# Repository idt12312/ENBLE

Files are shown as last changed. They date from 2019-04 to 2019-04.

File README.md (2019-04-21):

# ENBLE

ENBLE is the **EN**vironmental sensor which measures temperature, humidity, and air pressure and sends them over **BLE**.
Because it consumes little current, it can work several years.



Using bridge server and [ThingsBooard](https://thingsboard.io/) which are runnning on Raspberry Pi3, 
you can collect data from some ENBLEs and view measurement data via web browser.



## Contents of this repository

This repository consists of two components.

### 1. Sensor 

[**ENBLE/sensor**](sensor/)

It contains PCB design and firmware for a ENBLE device. 
The details is in README.md.

### 2. Bridge Server

[**ENBLE/bridge_server**](bridge_server/)

It constains a bridge between ENBLE and [**ThingsBooard**](https://thingsboard.io/) as a sample code to utilize ENBLE. 
Bridge server listens BLE advertise packets from ENBLEs and sends data to a ThingsBoard server. 
Using ThingsBoard enables you to collect and visualize measured data.

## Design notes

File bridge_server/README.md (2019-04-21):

# ENBLE Bridge Server

This program is a bridge between ENBLE and [**ThingsBooard**](https://thingsboard.io/) as a sample code to utilize ENBLE. 
It listens BLE advertise packets from ENBLEs and sends data to a ThingsBoard server. 
Using ThingsBoard enables you to collect and visualize measured data. 



## How to use
I tested this program on RaspberryPi3.
It may works well on the device which can execute python and has a Bluetooth interface.

Before running bridge_server.py, the following softwares and python packages need to install.

* Python3
* bluepy
* requests
* ThingsBoard

ThingsBoard is not necessary to run on the same device where bridge_server.py runs.

To run this program, you have to do the following.

1. Rename 'config.json.example' 'config.json'.
2. Edit config.json as your environment.
3. Run bridge_server.py.

If some error like the following occures,

```
bluepy.btle.BTLEManagementError: Failed to execute management command 'le on' (code: 20, error: Permission Denied)
```

execute the following.

```
setcap 'cap_net_raw,cap_net_admin+eip' {path_to_python_packages}/site-packages/bluepy/bluepy-helper
```

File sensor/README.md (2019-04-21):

# ENBLE Sensor 

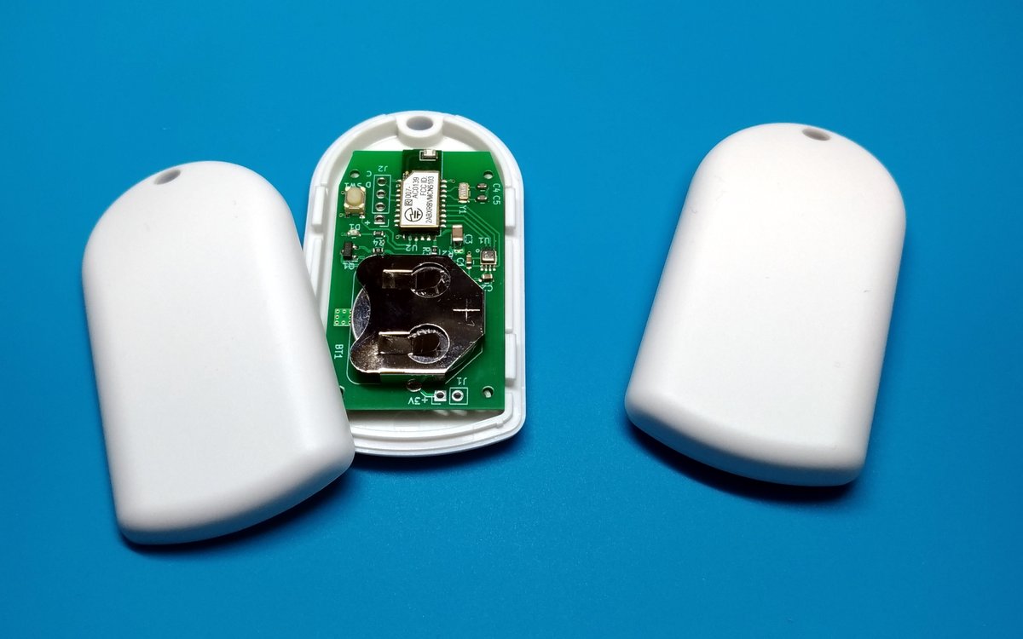
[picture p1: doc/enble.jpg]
ENBLE


This device measures temperature, humidity and pressure using BME280 and send these measured data over BLE advertising and GATT service.
The data format of BLE advertising and GATT service is described bellow.
Using advertising (not using GATT) to collect measured data enables a device to reduce current consumption.  

## BLE Advertise

| Parameter | Value |
|---|---|
| Local Name | "ENBLE" |
| Advertise Interval | 6000ms |
| Manufacturer data  | 10 bytes binary data  |

ENBLE has a push button.
If you push the button, advertising interval change into 100ms.
It is useful to find the specified device which you press the button. 

Manufacturer data has DeviceID and measurement results of sensors.  
Data format is as shown below. 

| Position | Contents | DataType |
|---|---|---|
| byte 0-1 | DeviceID | uint16 |
| byte 2-3 | Battery | uint16 |
| byte 4-5 | Temperature | int16 |
| byte 6-7 | Humidity | uint16 |
| byte 8-9 | Pressure | uint16 |

Each data is contained in **little endian 16bit integer**.  
Means of above data are same as ones in bellow characteristics.

## BLE Services

| Name | Type | Permissions | UUID | DataType |
|---|---|---|---|---|
| ENBLE Service | Service | Read | bff20001-378e-4955-89d6-25948b941062 | |
| DeviceID | Characteristic | Read, Write | bff20011-378e-4955-89d6-25948b941062 | uint16 |
|  Period | Characteristic | Read, Write | bff20012-378e-4955-89d6-25948b941062 | uint16 |
| Battery | Characteristic | Read | bff20021-378e-4955-89d6-25948b941062 | uint16 |
| Temperature | Characteristic | Read | bff20022-378e-4955-89d6-25948b941062 | int16 |
| Humidity | Characteristic | Read | bff20023-378e-4955-89d6-25948b941062 | uint16 |
| Pressure | Characteristic | Read | bff20024-378e-4955-89d6-25948b941062 | uint16 |

### DeviceID
This characteristic indicates a unique number as 16bit unsigned integer. 
The value of this characteristic is stored in nonvolatile memory. 

### Period
This characteristic indicates a sample period of sensors. 
All sensors (battery, temperature, humidity and pressure) sample at the same period. 
This period is 16 bit unsigned integer in seconds. 
The value of this characteristic is stored in nonvolatile memory. 

### Battery
This characteristic indicates battery voltage of the device in mV. 

### Temperature
This characteristic indicates temperature in degC, resolution is 0.01 DegC. 
A negative value is represented in two's complement number. 

### Humidity
This characteristic indicates humidity in %, resolution is 0.1 %.

### Pressure
This characteristic indicates air pressure in Pa, resolution is 10Pa

## Build

### Setup for build
1. Download Nordic SDK ver 12.3.0
2. Place Nordic SDK in firmware/lib  
ex) The structure of directory must be is following.   
    firmware/lib/  
        └──nRF5_SDK_12.3.0_d7731ad/ (this directory name can be anything you like)  
        .       ├──components/  
        .       ├──external/  
        .       ├── ......  

3. Modify NORDIC_SDK_PATH parameter in firmware/Makefile
4. Modify toolchain configuration in 
    * for Linux or OSX user : $(NORDIC_SDK_PATH)/components/toolchain/gcc/Makefile.posix
    * for Windows user : $(NORDIC_SDK_PATH)/components/toolchain/gcc/Makefile.windows

### Build and Flash firmware
This project can be build with GNU MAKE. 
What you need to do for build is executing ```make``` command. 
When you flah a firmware to an ENBLE sensor device, 
connect the device via JLink and execute ```make flash```.

## PCB

I design a PCB with KiCad. 

ENBLE's schematic

The following is a simple block diagram.



I designed PCB to fit in the case, [**TAKACHI PS-65 Seriese**](http://www.takachi-el.co.jp/data/pdf/2016-01-065.pdf). 

### Current consumption

| State | Consumption | Interval |
|---|---|---|
| advertising | 29.4 μC | 6.0 s |
| measuring (start) | 4.14 μC | 60 s |
| measuring (end) | 8.07 μC | 60 s |
| sleeping | 3.80 μA | constantly |

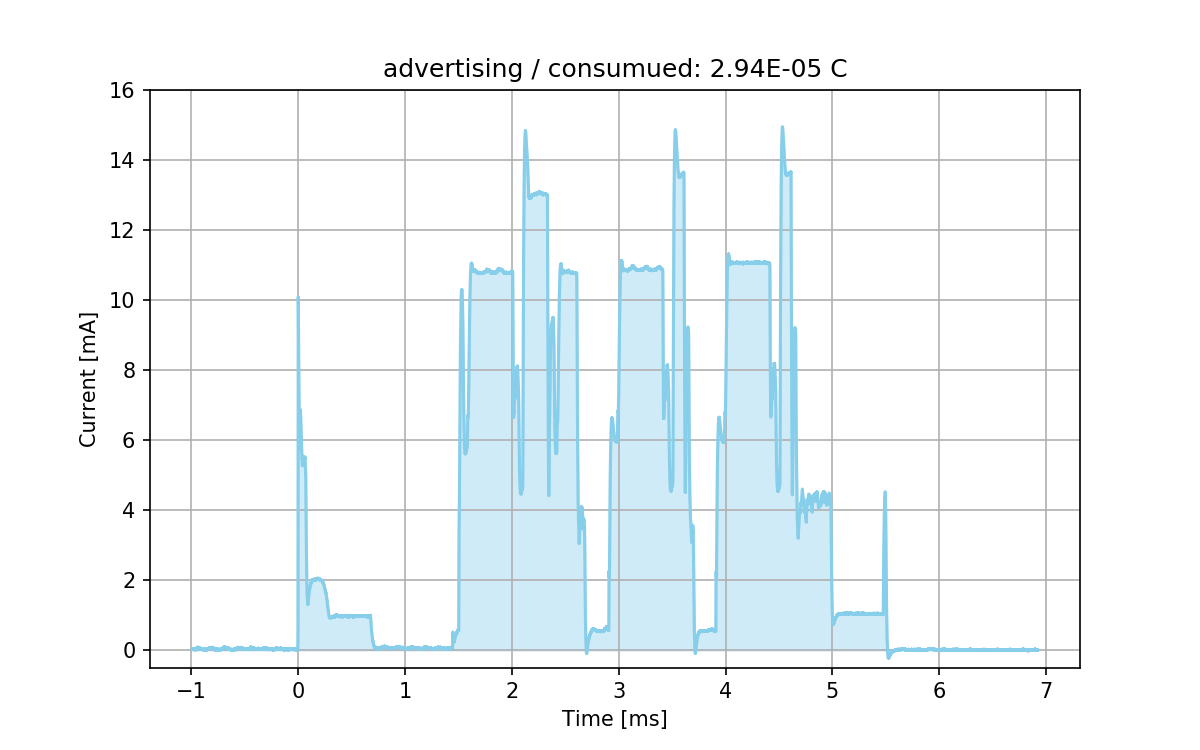
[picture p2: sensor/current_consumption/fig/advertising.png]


<table border="0">
    <tr>
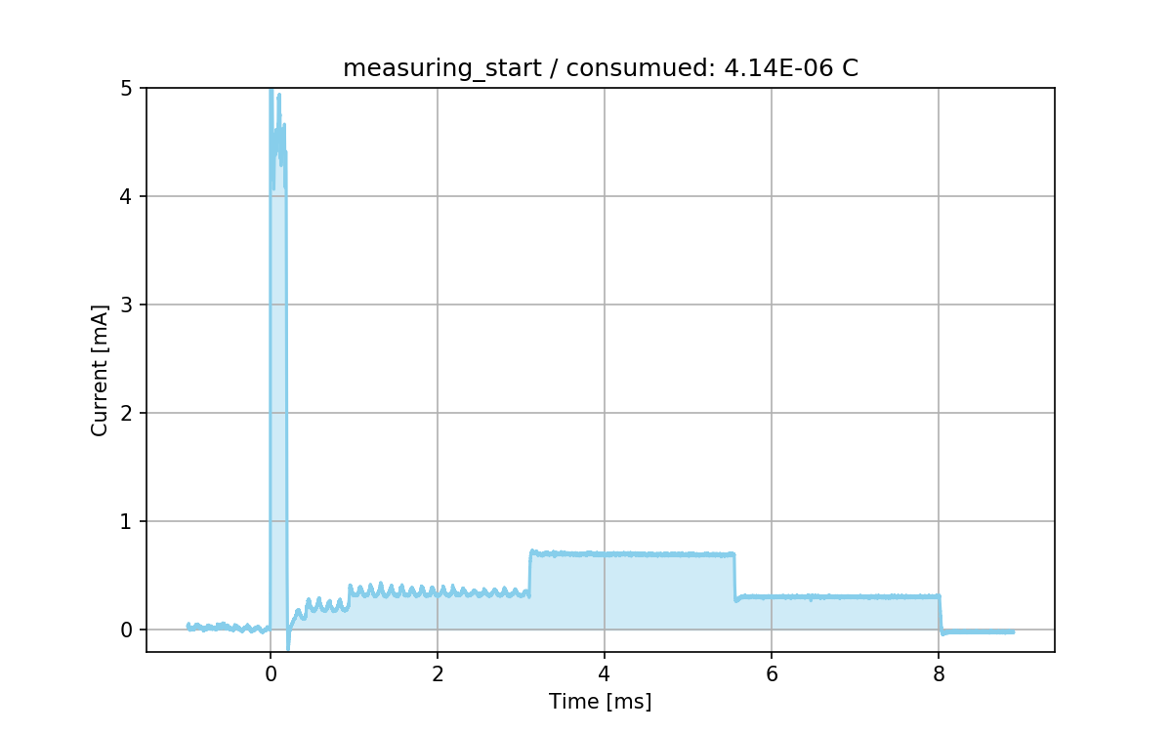
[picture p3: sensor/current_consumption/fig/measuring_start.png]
        <td></td>
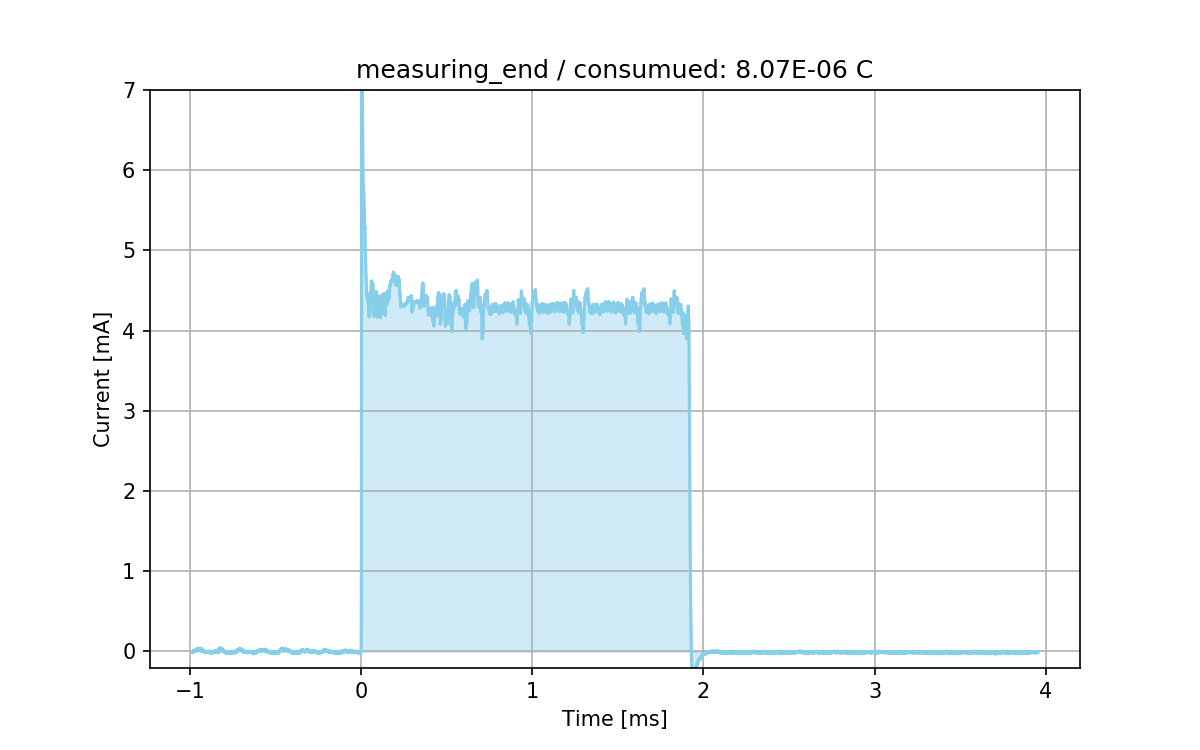
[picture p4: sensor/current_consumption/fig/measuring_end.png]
        <td></td>
    </tr>
</table>

From the above, current consumption per one hour is  
3600 / 6 * 29.4μ + 3600 / 60 * (4.14μ + 8.07μ) + 3600 * 3.8μ = 32.1 mC/h.

Because CR2032 battery charge is 810C(225mAh), 
ENBLE can work in
810 / 31.6e-3 = 25233h (**about 3 years**).

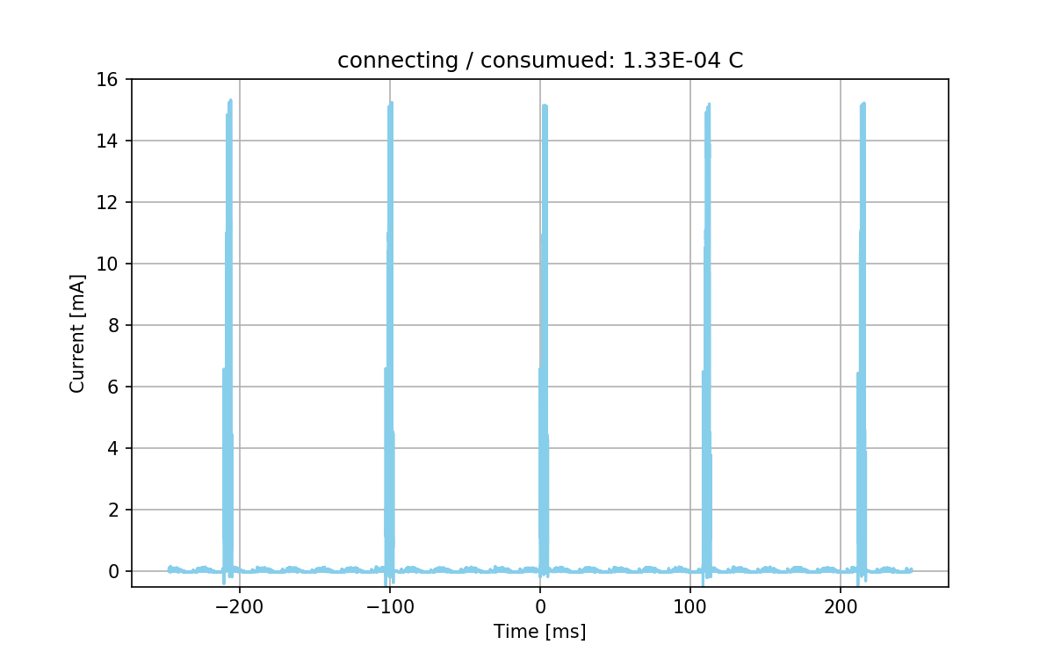
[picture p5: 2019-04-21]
sensor/current_consumption/fig/connecting.png

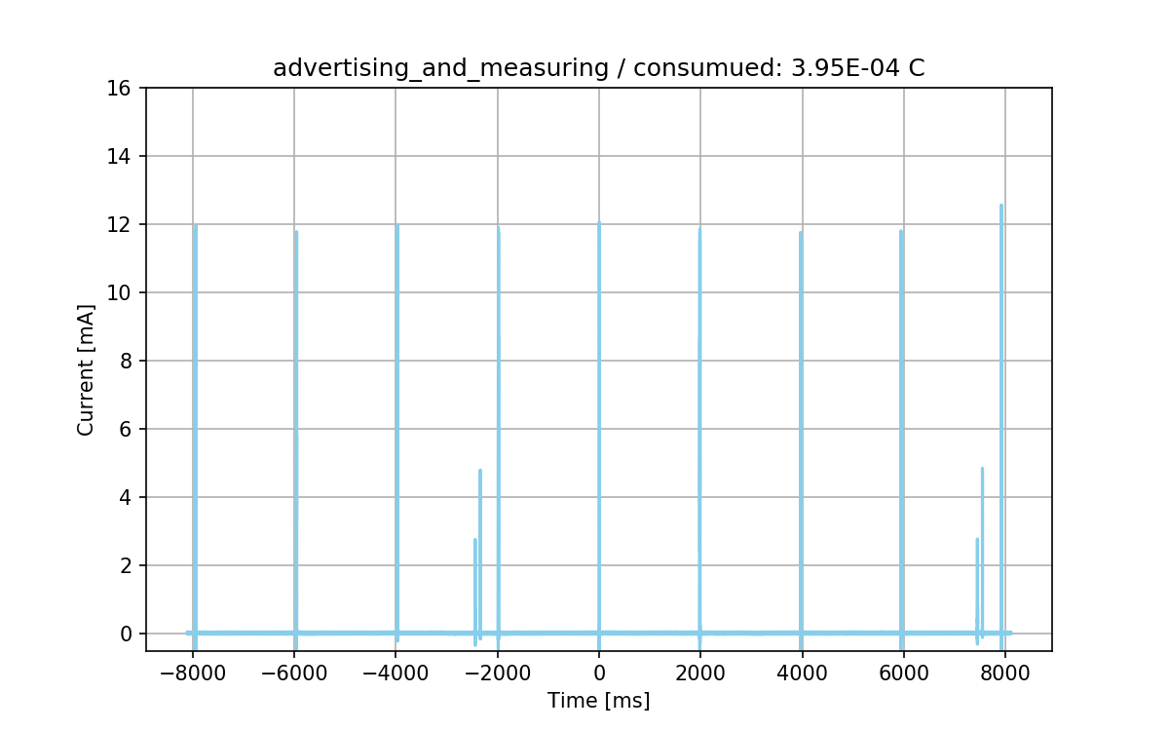
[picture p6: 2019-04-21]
sensor/current_consumption/fig/advertising_and_measuring.png

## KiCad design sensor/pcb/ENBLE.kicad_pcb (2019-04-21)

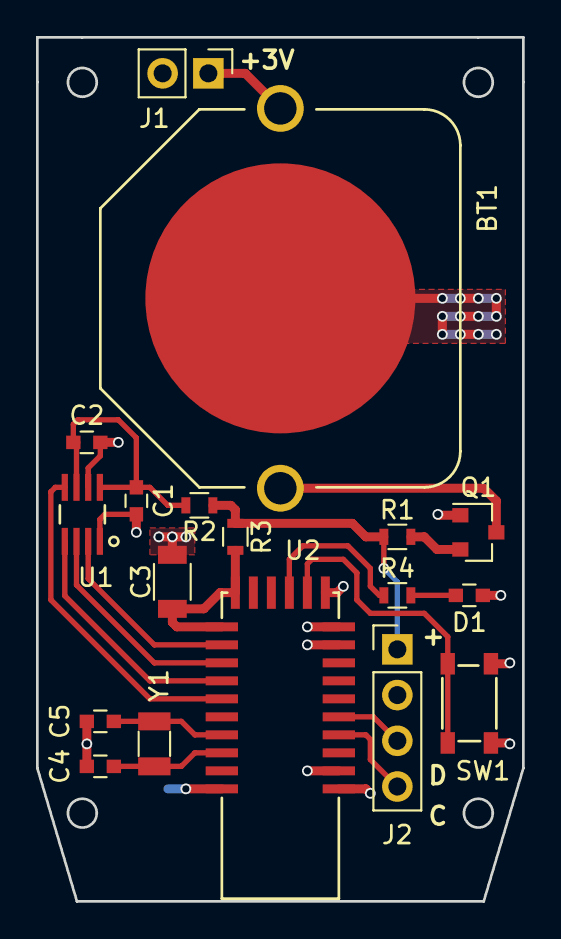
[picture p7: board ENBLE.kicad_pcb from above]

Board: 2 copper layers, 27.0 x 48.0 mm, 18 parts (0 on the bottom side), 17 nets.

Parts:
BT1: CR2032; BK-888
C1, C2: 0.1u; C_0603
C3: 10u; C_1206
C4, C5: 8p; C_0603
D1: LED; C_0603
J1: Conn_01x02; Pin_Header_Straight_1x02_Pitch2.54mm
J2: Conn_01x04; Pin_Header_Straight_1x04_Pitch2.54mm
Q1: SI2333; SOT-23
R1, R2, R3: 0; R_0603
R4: 2.2k; R_0603
SW1: SW_SPST; SKRPACE010
U1: BME280
U2: BVMCN5103-BK
Y1: 32.768kHz; Crystal_SMD_3215-2pin_3.2x1.5mm

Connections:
/LED: R4.1, U2.13
/SENS_CS: U1.2, U2.18
/SENS_SCK: U1.4, U2.20
/SENS_SDI: U1.3, U2.19
/SENS_SDO: U1.5, U2.21
/SW: SW1.1, U2.12
/SWDCLK: J2.4, U2.4
/SWDIO: J2.3, U2.5
GND: BT1.2, C1.2, C2.2, C3.2, C4.2, C5.2, D1.1, J1.2, J2.2, Q1.1, SW1.2, U1.1, U1.7, U2.1, U2.2, U2.9, U2.10, U2.11, U2.26
unnamed: BT1.1, J1.1, Q1.3
unnamed: C1.1, C2.1, R2.2, U1.6, U1.8
unnamed: C3.1, R3.2, U2.16, U2.17
unnamed: C4.1, U2.24, Y1.1
unnamed: C5.1, U2.23, Y1.2
unnamed: D1.2, R4.2
unnamed: Q1.2, R1.1
VCC: J2.1, R1.2, R2.1, R3.1

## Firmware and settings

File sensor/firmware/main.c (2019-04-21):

/**
 * Copyright (c) 2014 - 2017, Nordic Semiconductor ASA
 * 
 * All rights reserved.
 * 
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
 * 3. Neither the name of Nordic Semiconductor ASA nor the names of its
 *    contributors may be used to endorse or promote products derived from this
 *    software without specific prior written permission.
 * 
 * 4. This software, with or without modification, must only be used with a
 *    Nordic Semiconductor ASA integrated circuit.
 * 
 * 5. Any software provided in binary form under this license must not be reverse
 *    engineered, decompiled, modified and/or disassembled.
 * 
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
 */

/** @file
 *
 * @defgroup ble_sdk_app_template_main main.c
 * @{
 * @ingroup ble_sdk_app_template
 * @brief Template project main file.
 *
 * This file contains a template for creating a new application. It has the code necessary to wakeup
 * from button, advertise, get a connection restart advertising on disconnect and if no new
 * connection created go back to system-off mode.
 * It can easily be used as a starting point for creating a new application, the comments identified
 * with 'YOUR_JOB' indicates where and how you can customize.
 */

#include <stdbool.h>
#include <stdint.h>
#include <string.h>

#include "nordic_common.h"
#include "nrf.h"
#include "app_error.h"
#include "ble.h"
#include "ble_srv_common.h"
#include "ble_advdata.h"
#include "ble_advertising.h"
#include "ble_conn_params.h"
#include "softdevice_handler.h"
#include "app_timer.h"
#include "fstorage.h"
#include "fds.h"
#include "peer_manager.h"

#include "nrf_gpio.h"
#include "ble_advdata.h"
#include "ble_advertising.h"
#include "ble_conn_state.h"

#include "nrf_drv_clock.h"

#include "ble_enble.h"
#include "app_enble.h"

#define NRF_LOG_MODULE_NAME "MAIN"
#define NRF_LOG_LEVEL 0
#include "nrf_log.h"
#include "nrf_log_ctrl.h"

#define IS_SRVC_CHANGED_CHARACT_PRESENT 1 /**< Include or not the service_changed characteristic. if not enabled, the server's database cannot be changed for the lifetime of the device*/

#if (NRF_SD_BLE_API_VERSION == 3)
#define NRF_BLE_MAX_MTU_SIZE GATT_MTU_SIZE_DEFAULT /**< MTU size used in the softdevice enabling and to reply to a BLE_GATTS_EVT_EXCHANGE_MTU_REQUEST event. */
#endif

#define APP_FEATURE_NOT_SUPPORTED BLE_GATT_STATUS_ATTERR_APP_BEGIN + 2 /**< Reply when unsupported features are requested. */

#define CENTRAL_LINK_COUNT 0    /**< Number of central links used by the application. When changing this number remember to adjust the RAM settings*/
#define PERIPHERAL_LINK_COUNT 1 /**< Number of peripheral links used by the application. When changing this number remember to adjust the RAM settings*/

#define DEVICE_NAME "ENBLE"                     /**< Name of device. Will be included in the advertising data. */

#define APP_TIMER_PRESCALER 0     /**< Value of the RTC1 PRESCALER register. */
#define APP_TIMER_OP_QUEUE_SIZE 4 /**< Size of timer operation queues. */

#define MIN_CONN_INTERVAL MSEC_TO_UNITS(100, UNIT_1_25_MS) /**< Minimum acceptable connection interval (0.1 seconds). */
#define MAX_CONN_INTERVAL MSEC_TO_UNITS(200, UNIT_1_25_MS) /**< Maximum acceptable connection interval (0.2 second). */
#define SLAVE_LATENCY 0                                    /**< Slave latency. */
#define CONN_SUP_TIMEOUT MSEC_TO_UNITS(4000, UNIT_10_MS)   /**< Connection supervisory timeout (4 seconds). */

#define FIRST_CONN_PARAMS_UPDATE_DELAY APP_TIMER_TICKS(5000, APP_TIMER_PRESCALER) /**< Time from initiating event (connect or start of notification) to first time sd_ble_gap_conn_param_update is called (5 seconds). */
#define NEXT_CONN_PARAMS_UPDATE_DELAY APP_TIMER_TICKS(30000, APP_TIMER_PRESCALER) /**< Time between each call to sd_ble_gap_conn_param_update after the first call (30 seconds). */
#define MAX_CONN_PARAMS_UPDATE_COUNT 3                                            /**< Number of attempts before giving up the connection parameter negotiation. */

#define SEC_PARAM_BOND 1                               /**< Perform bonding. */
#define SEC_PARAM_MITM 0                               /**< Man In The Middle protection not required. */
#define SEC_PARAM_LESC 0                               /**< LE Secure Connections not enabled. */
#define SEC_PARAM_KEYPRESS 0                           /**< Keypress notifications not enabled. */
#define SEC_PARAM_IO_CAPABILITIES BLE_GAP_IO_CAPS_NONE /**< No I/O capabilities. */
#define SEC_PARAM_OOB 0                                /**< Out Of Band data not available. */
#define SEC_PARAM_MIN_KEY_SIZE 7                       /**< Minimum encryption key size. */
#define SEC_PARAM_MAX_KEY_SIZE 16                      /**< Maximum encryption key size. */

#define DEAD_BEEF 0xDEADBEEF /**< Value used as error code on stack dump, can be used to identify stack location on stack unwind. */

static uint16_t m_conn_handle = BLE_CONN_HANDLE_INVALID; /**< Handle of the current connection. */

static ble_enble_t m_enble_instance;


void app_error_fault_handler(uint32_t id, uint32_t pc, uint32_t info)
{
	error_info_t *error_info = (error_info_t*)info;
	printf("[APP_ERROR] code %lu at %s:%u\n",
			error_info->err_code,
			error_info->p_file_name,
			error_info->line_num);
}


void assert_nrf_callback(uint16_t line_num, const uint8_t * p_file_name)
{
    app_error_handler(DEAD_BEEF, line_num, p_file_name);
}


/**@brief Function for handling Peer Manager events.
 *
 * @param[in] p_evt  Peer Manager event.
 */
static void pm_evt_handler(pm_evt_t const *p_evt)
{
    ret_code_t err_code;

    switch (p_evt->evt_id)
    {
    case PM_EVT_BONDED_PEER_CONNECTED:
    {
        NRF_LOG_INFO("Connected to a previously bonded device.\r\n");
    }
    break;

    case PM_EVT_CONN_SEC_SUCCEEDED:
    {
        NRF_LOG_INFO("Connection secured. Role: %d. conn_handle: %d, Procedure: %d\r\n",
                     ble_conn_state_role(p_evt->conn_handle),
                     p_evt->conn_handle,
                     p_evt->params.conn_sec_succeeded.procedure);
    }
    break;

    case PM_EVT_CONN_SEC_FAILED:
    {
        /* Often, when securing fails, it shouldn't be restarted, for security reasons.
             * Other times, it can be restarted directly.
             * Sometimes it can be restarted, but only after changing some Security Parameters.
             * Sometimes, it cannot be restarted until the link is disconnected and reconnected.
             * Sometimes it is impossible, to secure the link, or the peer device does not support it.
             * How to handle this error is highly application dependent. */
    }
    break;

    case PM_EVT_CONN_SEC_CONFIG_REQ:
    {
        // Reject pairing request from an already bonded peer.
        pm_conn_sec_config_t conn_sec_config = {.allow_repairing = false};
        pm_conn_sec_config_reply(p_evt->conn_handle, &conn_sec_config);
    }
    break;

    case PM_EVT_STORAGE_FULL:
    {
        // Run garbage collection on the flash.
        err_code = fds_gc();
        if (err_code == FDS_ERR_BUSY || err_code == FDS_ERR_NO_SPACE_IN_QUEUES)
        {
            // Retry.
        }
        else
        {
            APP_ERROR_CHECK(err_code);
        }
    }
    break;

    case PM_EVT_PEERS_DELETE_SUCCEEDED:
    {
        err_code = ble_advertising_start(BLE_ADV_MODE_SLOW);
        APP_ERROR_CHECK(err_code);
    }
    break;

    case PM_EVT_LOCAL_DB_CACHE_APPLY_FAILED:
    {
        // The local database has likely changed, send service changed indications.
        pm_local_database_has_changed();
    }
    break;

    case PM_EVT_PEER_DATA_UPDATE_FAILED:
    {
        // Assert.
        APP_ERROR_CHECK(p_evt->params.peer_data_update_failed.error);
    }
    break;

    case PM_EVT_PEER_DELETE_FAILED:
    {
        // Assert.
        APP_ERROR_CHECK(p_evt->params.peer_delete_failed.error);
    }
    break;

    case PM_EVT_PEERS_DELETE_FAILED:
    {
        // Assert.
        APP_ERROR_CHECK(p_evt->params.peers_delete_failed_evt.error);
    }
    break;

    case PM_EVT_ERROR_UNEXPECTED:
    {
        // Assert.
        APP_ERROR_CHECK(p_evt->params.error_unexpected.error);
    }
    break;

    case PM_EVT_CONN_SEC_START:
    case PM_EVT_PEER_DATA_UPDATE_SUCCEEDED:
    case PM_EVT_PEER_DELETE_SUCCEEDED:
    case PM_EVT_LOCAL_DB_CACHE_APPLIED:
    case PM_EVT_SERVICE_CHANGED_IND_SENT:
    case PM_EVT_SERVICE_CHANGED_IND_CONFIRMED:
    default:
        break;
    }
}

/**@brief Function for the Timer initialization.
 *
 * @details Initializes the timer module. This creates and starts application timers.
 */
static void timers_init(void)
{

    // Initialize timer module.
    APP_TIMER_INIT(APP_TIMER_PRESCALER, APP_TIMER_OP_QUEUE_SIZE, false);

    // Create timers.

    /* YOUR_JOB: Create any timers to be used by the application.
                 Below is an example of how to create a timer.
                 For every new timer needed, increase the value of the macro APP_TIMER_MAX_TIMERS by
                 one.
       uint32_t err_code;
       err_code = app_timer_create(&m_app_timer_id, APP_TIMER_MODE_REPEATED, timer_timeout_handler);
       APP_ERROR_CHECK(err_code); */
}

/**@brief Function for the GAP initialization.
 *
 * @details This function sets up all the necessary GAP (Generic Access Profile) parameters of the
 *          device including the device name, appearance, and the preferred connection parameters.
 */
static void gap_params_init(void)
{
    uint32_t err_code;
    ble_gap_conn_params_t gap_conn_params;
    ble_gap_conn_sec_mode_t sec_mode;

    BLE_GAP_CONN_SEC_MODE_SET_OPEN(&sec_mode);

    err_code = sd_ble_gap_device_name_set(&sec_mode,
                                          (const uint8_t *)DEVICE_NAME,
                                          strlen(DEVICE_NAME));
    APP_ERROR_CHECK(err_code);

    /* YOUR_JOB: Use an appearance value matching the application's use case.
       err_code = sd_ble_gap_appearance_set(BLE_APPEARANCE_);
       APP_ERROR_CHECK(err_code); */

    memset(&gap_conn_params, 0, sizeof(gap_conn_params));

    gap_conn_params.min_conn_interval = MIN_CONN_INTERVAL;
    gap_conn_params.max_conn_interval = MAX_CONN_INTERVAL;
    gap_conn_params.slave_latency = SLAVE_LATENCY;
    gap_conn_params.conn_sup_timeout = CONN_SUP_TIMEOUT;

    err_code = sd_ble_gap_ppcp_set(&gap_conn_params);
    APP_ERROR_CHECK(err_code);
}

/**@brief Function for handling the Enble Service events. 
 *
 * @details This function will be called for all YY Service events which are passed to
 *          the application.
 *
 * @param[in]   p_yy_service   YY Service structure.
 * @param[in]   p_evt          Event received from the YY Service.
 *
 */
static void on_enble_device_id_update_evt(ble_enble_t *p_enble, uint16_t new_value)
{
    app_enble_on_device_id_update_evt(new_value);
}

/**@brief Function for handling the Enble Service events. 
 *
 * @details This function will be called for all YY Service events which are passed to
 *          the application.
 *
 * @param[in]   p_yy_service   YY Service structure.
 * @param[in]   p_evt          Event received from the YY Service.
 *
 */
static void on_enble_period_update_evt(ble_enble_t *p_enble, uint16_t new_value)
{
    app_enble_on_period_update_evt(new_value);
}

/**@brief Function for initializing services that will be used by the application.
 */
static void services_init(void)
{
    uint32_t err_code;
    ble_enble_init_t enble_init;

    enble_init.device_id_update_handler = on_enble_device_id_update_evt;
    enble_init.period_update_handler = on_enble_period_update_evt;

    err_code = ble_enble_init(&m_enble_instance, &enble_init);
    APP_ERROR_CHECK(err_code);
}

/**@brief Function for handling the Connection Parameters Module.
 *
 * @details This function will be called for all events in the Connection Parameters Module which
 *          are passed to the application.
 *          @note All this function does is to disconnect. This could have been done by simply
 *                setting the disconnect_on_fail config parameter, but instead we use the event
 *                handler mechanism to demonstrate its use.
 *
 * @param[in] p_evt  Event received from the Connection Parameters Module.
 */
static void on_conn_params_evt(ble_conn_params_evt_t *p_evt)
{
    uint32_t err_code;

    if (p_evt->evt_type == BLE_CONN_PARAMS_EVT_FAILED)
    {
        err_code = sd_ble_gap_disconnect(m_conn_handle, BLE_HCI_CONN_INTERVAL_UNACCEPTABLE);
        APP_ERROR_CHECK(err_code);
    }
}

/**@brief Function for handling a Connection Parameters error.
 *
 * @param[in] nrf_error  Error code containing information about what went wrong.
 */
static void conn_params_error_handler(uint32_t nrf_error)
{
    APP_ERROR_HANDLER(nrf_error);
}

/**@brief Function for initializing the Connection Parameters module.
 */
static void conn_params_init(void)
{
    uint32_t err_code;
    ble_conn_params_init_t cp_init;

    memset(&cp_init, 0, sizeof(cp_init));

    cp_init.p_conn_params = NULL;
    cp_init.first_conn_params_update_delay = FIRST_CONN_PARAMS_UPDATE_DELAY;
    cp_init.next_conn_params_update_delay = NEXT_CONN_PARAMS_UPDATE_DELAY;
    cp_init.max_conn_params_update_count = MAX_CONN_PARAMS_UPDATE_COUNT;
    cp_init.start_on_notify_cccd_handle = BLE_GATT_HANDLE_INVALID;
    cp_init.disconnect_on_fail = false;
    cp_init.evt_handler = on_conn_params_evt;
    cp_init.error_handler = conn_params_error_handler;

    err_code = ble_conn_params_init(&cp_init);
    APP_ERROR_CHECK(err_code);
}

/**@brief Function for handling the Application's BLE Stack events.
 *
 * @param[in] p_ble_evt  Bluetooth stack event.
 */
static void on_ble_evt(ble_evt_t *p_ble_evt)
{
    uint32_t err_code = NRF_SUCCESS;

    switch (p_ble_evt->header.evt_id)
    {
    case BLE_GAP_EVT_DISCONNECTED:
        NRF_LOG_INFO("Disconnected.\r\n");
        APP_ERROR_CHECK(err_code);
        
        err_code = ble_advertising_start(BLE_ADV_MODE_SLOW);
        APP_ERROR_CHECK(err_code);
        
        break; // BLE_GAP_EVT_DISCONNECTED

    case BLE_GAP_EVT_CONNECTED:
        NRF_LOG_INFO("Connected.\r\n");
        APP_ERROR_CHECK(err_code);
        m_conn_handle = p_ble_evt->evt.gap_evt.conn_handle;
        break; // BLE_GAP_EVT_CONNECTED

    case BLE_GATTC_EVT_TIMEOUT:
        // Disconnect on GATT Client timeout event.
        NRF_LOG_DEBUG("GATT Client Timeout.\r\n");
        err_code = sd_ble_gap_disconnect(p_ble_evt->evt.gattc_evt.conn_handle,
                                         BLE_HCI_REMOTE_USER_TERMINATED_CONNECTION);
        APP_ERROR_CHECK(err_code);
        break; // BLE_GATTC_EVT_TIMEOUT

    case BLE_GATTS_EVT_TIMEOUT:
        // Disconnect on GATT Server timeout event.
        NRF_LOG_DEBUG("GATT Server Timeout.\r\n");
        err_code = sd_ble_gap_disconnect(p_ble_evt->evt.gatts_evt.conn_handle,
                                         BLE_HCI_REMOTE_USER_TERMINATED_CONNECTION);
        APP_ERROR_CHECK(err_code);
        break; // BLE_GATTS_EVT_TIMEOUT

    case BLE_EVT_USER_MEM_REQUEST:
        err_code = sd_ble_user_mem_reply(p_ble_evt->evt.gattc_evt.conn_handle, NULL);
        APP_ERROR_CHECK(err_code);
        break; // BLE_EVT_USER_MEM_REQUEST

    case BLE_GATTS_EVT_RW_AUTHORIZE_REQUEST:
    {
        ble_gatts_evt_rw_authorize_request_t req;
        ble_gatts_rw_authorize_reply_params_t auth_reply;

        req = p_ble_evt->evt.gatts_evt.params.authorize_request;

        if (req.type != BLE_GATTS_AUTHORIZE_TYPE_INVALID)
        {
            if ((req.request.write.op == BLE_GATTS_OP_PREP_WRITE_REQ) ||
                (req.request.write.op == BLE_GATTS_OP_EXEC_WRITE_REQ_NOW) ||
                (req.request.write.op == BLE_GATTS_OP_EXEC_WRITE_REQ_CANCEL))
            {
                if (req.type == BLE_GATTS_AUTHORIZE_TYPE_WRITE)
                {
                    auth_reply.type = BLE_GATTS_AUTHORIZE_TYPE_WRITE;
                }
                else
                {
                    auth_reply.type = BLE_GATTS_AUTHORIZE_TYPE_READ;
                }
                auth_reply.params.write.gatt_status = APP_FEATURE_NOT_SUPPORTED;
                err_code = sd_ble_gatts_rw_authorize_reply(p_ble_evt->evt.gatts_evt.conn_handle,
                                                           &auth_reply);
                APP_ERROR_CHECK(err_code);
            }
        }
    }
    break; // BLE_GATTS_EVT_RW_AUTHORIZE_REQUEST

#if (NRF_SD_BLE_API_VERSION == 3)
    case BLE_GATTS_EVT_EXCHANGE_MTU_REQUEST:
        err_code = sd_ble_gatts_exchange_mtu_reply(p_ble_evt->evt.gatts_evt.conn_handle,
                                                   NRF_BLE_MAX_MTU_SIZE);
        APP_ERROR_CHECK(err_code);
        break; // BLE_GATTS_EVT_EXCHANGE_MTU_REQUEST
#endif

    default:
        // No implementation needed.
        break;
    }
}

/**@brief Function for dispatching a BLE stack event to all modules with a BLE stack event handler.
 *
 * @details This function is called from the BLE Stack event interrupt handler after a BLE stack
 *          event has been received.
 *
 * @param[in] p_ble_evt  Bluetooth stack event.
 */
static void ble_evt_dispatch(ble_evt_t *p_ble_evt)
{
    /** The Connection state module has to be fed BLE events in order to function correctly
     * Remember to call ble_conn_state_on_ble_evt before calling any ble_conns_state_* functions. */
    ble_conn_state_on_ble_evt(p_ble_evt);
    pm_on_ble_evt(p_ble_evt);
    ble_conn_params_on_ble_evt(p_ble_evt);
    on_ble_evt(p_ble_evt);
    ble_advertising_on_ble_evt(p_ble_evt);
    ble_enble_on_ble_evt(&m_enble_instance, p_ble_evt);
}

/**@brief Function for dispatching a system event to interested modules.
 *
 * @details This function is called from the System event interrupt handler after a system
 *          event has been received.
 *
 * @param[in] sys_evt  System stack event.
 */
static void sys_evt_dispatch(uint32_t sys_evt)
{
    // Dispatch the system event to the fstorage module, where it will be
    // dispatched to the Flash Data Storage (FDS) module.
    fs_sys_event_handler(sys_evt);

    // Dispatch to the Advertising module last, since it will check if there are any
    // pending flash operations in fstorage. Let fstorage process system events first,
    // so that it can report correctly to the Advertising module.
    ble_advertising_on_sys_evt(sys_evt);
}

/**@brief Function for initializing the BLE stack.
 *
 * @details Initializes the SoftDevice and the BLE event interrupt.
 */
static void ble_stack_init(void)
{
    uint32_t err_code;

    nrf_clock_lf_cfg_t clock_lf_cfg = {
        .source = NRF_CLOCK_LF_SRC_XTAL,
        .rc_ctiv = 0,
        .rc_temp_ctiv = 0,
        .xtal_accuracy = NRF_CLOCK_LF_XTAL_ACCURACY_20_PPM};

    // Initialize the SoftDevice handler module.
    SOFTDEVICE_HANDLER_INIT(&clock_lf_cfg, NULL);

    ble_enable_params_t ble_enable_params;
    err_code = softdevice_enable_get_default_config(CENTRAL_LINK_COUNT,
                                                    PERIPHERAL_LINK_COUNT,
                                                    &ble_enable_params);
    APP_ERROR_CHECK(err_code);

    // Check the ram settings against the used number of links
    CHECK_RAM_START_ADDR(CENTRAL_LINK_COUNT, PERIPHERAL_LINK_COUNT);

    // Enable BLE stack.
#if (NRF_SD_BLE_API_VERSION == 3)
    ble_enable_params.gatt_enable_params.att_mtu = NRF_BLE_MAX_MTU_SIZE;
#endif
    err_code = softdevice_enable(&ble_enable_params);
    APP_ERROR_CHECK(err_code);

    // Register with the SoftDevice handler module for BLE events.
    err_code = softdevice_ble_evt_handler_set(ble_evt_dispatch);
    APP_ERROR_CHECK(err_code);

    // Register with the SoftDevice handler module for BLE events.
    err_code = softdevice_sys_evt_handler_set(sys_evt_dispatch);
    APP_ERROR_CHECK(err_code);
}

/**@brief Function for the Peer Manager initialization.
 */
static void peer_manager_init()
{
    ble_gap_sec_params_t sec_param;
    ret_code_t err_code;

    err_code = pm_init();
    APP_ERROR_CHECK(err_code);

    memset(&sec_param, 0, sizeof(ble_gap_sec_params_t));

    // Security parameters to be used for all security procedures.
    sec_param.bond = SEC_PARAM_BOND;
    sec_param.mitm = SEC_PARAM_MITM;
    sec_param.lesc = SEC_PARAM_LESC;
    sec_param.keypress = SEC_PARAM_KEYPRESS;
    sec_param.io_caps = SEC_PARAM_IO_CAPABILITIES;
    sec_param.oob = SEC_PARAM_OOB;
    sec_param.min_key_size = SEC_PARAM_MIN_KEY_SIZE;
    sec_param.max_key_size = SEC_PARAM_MAX_KEY_SIZE;
    sec_param.kdist_own.enc = 1;
    sec_param.kdist_own.id = 1;
    sec_param.kdist_peer.enc = 1;
    sec_param.kdist_peer.id = 1;

    err_code = pm_sec_params_set(&sec_param);
    APP_ERROR_CHECK(err_code);

    err_code = pm_register(pm_evt_handler);
    APP_ERROR_CHECK(err_code);
}

/**@brief Function for the Power manager.
 */
static void power_manage(void)
{
    uint32_t err_code = sd_app_evt_wait();

    APP_ERROR_CHECK(err_code);
}

/**@brief Function for application main entry.
 */
int main(void)
{
    uint32_t err_code;

    // Initialize.
    err_code = NRF_LOG_INIT(NULL);
    APP_ERROR_CHECK(err_code);

    timers_init();
    ble_stack_init();

    peer_manager_init();

    gap_params_init();
    services_init();
    conn_params_init();

    // Start execution.
    NRF_LOG_INFO("ENBLE started\r\n");
    err_code = app_enble_init(&m_enble_instance);
    APP_ERROR_CHECK(err_code);

    // Enter main loop.
    for (;;)
    {
        if (NRF_LOG_PROCESS() == false)
        {
            power_manage();
        }
    }
}

/**
 * @}
 */

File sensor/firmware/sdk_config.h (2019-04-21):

#ifndef SDK_CONFIG_H
#define SDK_CONFIG_H
// <<< Use Configuration Wizard in Context Menu >>>\n
#ifdef USE_APP_CONFIG
#include "app_config.h"
#endif
// <h> nRF_BLE 

//==========================================================
// <q> BLE_ADVERTISING_ENABLED  - ble_advertising - Advertising module
 

#ifndef BLE_ADVERTISING_ENABLED
#define BLE_ADVERTISING_ENABLED 1
#endif

// <q> BLE_DTM_ENABLED  - ble_dtm - Module for testing RF/PHY using DTM commands
 

#ifndef BLE_DTM_ENABLED
#define BLE_DTM_ENABLED 0
#endif

// <q> BLE_RACP_ENABLED  - ble_racp - Record Access Control Point library
 

#ifndef BLE_RACP_ENABLED
#define BLE_RACP_ENABLED 0
#endif

// <q> NRF_BLE_QWR_ENABLED  - nrf_ble_qwr - Queued writes support module (prepare/execute write)
 

#ifndef NRF_BLE_QWR_ENABLED
#define NRF_BLE_QWR_ENABLED 0
#endif

// <q> PEER_MANAGER_ENABLED  - peer_manager - Peer Manager
 

#ifndef PEER_MANAGER_ENABLED
#define PEER_MANAGER_ENABLED 1
#endif

// </h> 
//==========================================================

// <h> nRF_BLE_Services 

//==========================================================
// <q> BLE_ANCS_C_ENABLED  - ble_ancs_c - Apple Notification Service Client
 

#ifndef BLE_ANCS_C_ENABLED
#define BLE_ANCS_C_ENABLED 0
#endif

// <q> BLE_ANS_C_ENABLED  - ble_ans_c - Alert Notification Service Client
 

#ifndef BLE_ANS_C_ENABLED
#define BLE_ANS_C_ENABLED 0
#endif

// <q> BLE_BAS_C_ENABLED  - ble_bas_c - Battery Service Client
 

#ifndef BLE_BAS_C_ENABLED
#define BLE_BAS_C_ENABLED 0
#endif

// <q> BLE_BAS_ENABLED  - ble_bas - Battery Service
 

#ifndef BLE_BAS_ENABLED
#define BLE_BAS_ENABLED 0
#endif

// <q> BLE_CSCS_ENABLED  - ble_cscs - Cycling Speed and Cadence Service
 

#ifndef BLE_CSCS_ENABLED
#define BLE_CSCS_ENABLED 0
#endif

// <q> BLE_CTS_C_ENABLED  - ble_cts_c - Current Time Service Client
 

#ifndef BLE_CTS_C_ENABLED
#define BLE_CTS_C_ENABLED 0
#endif

// <q> BLE_DIS_ENABLED  - ble_dis - Device Information Service
 

#ifndef BLE_DIS_ENABLED
#define BLE_DIS_ENABLED 0
#endif

// <q> BLE_GLS_ENABLED  - ble_gls - Glucose Service
 

#ifndef BLE_GLS_ENABLED
#define BLE_GLS_ENABLED 0
#endif

// <q> BLE_HIDS_ENABLED  - ble_hids - Human Interface Device Service
 

#ifndef BLE_HIDS_ENABLED
#define BLE_HIDS_ENABLED 0
#endif

// <e> BLE_HRS_C_ENABLED - ble_hrs_c - Heart Rate Service Client
//==========================================================
#ifndef BLE_HRS_C_ENABLED
#define BLE_HRS_C_ENABLED 0
#endif
#if  BLE_HRS_C_ENABLED
// <o> BLE_HRS_C_RR_INTERVALS_MAX_CNT - Maximum number of RR_INTERVALS per notification to be decoded 
#ifndef BLE_HRS_C_RR_INTERVALS_MAX_CNT
#define BLE_HRS_C_RR_INTERVALS_MAX_CNT 30
#endif

#endif //BLE_HRS_C_ENABLED
// </e>

// <q> BLE_HRS_ENABLED  - ble_hrs - Heart Rate Service
 

#ifndef BLE_HRS_ENABLED
#define BLE_HRS_ENABLED 0
#endif

// <q> BLE_HTS_ENABLED  - ble_hts - Health Thermometer Service
 

#ifndef BLE_HTS_ENABLED
#define BLE_HTS_ENABLED 0
#endif

// <q> BLE_IAS_C_ENABLED  - ble_ias_c - Immediate Alert Service Client
 

#ifndef BLE_IAS_C_ENABLED
#define BLE_IAS_C_ENABLED 0
#endif

// <q> BLE_IAS_ENABLED  - ble_ias - Immediate Alert Service
 

#ifndef BLE_IAS_ENABLED
#define BLE_IAS_ENABLED 0
#endif

// <q> BLE_LBS_C_ENABLED  - ble_lbs_c - Nordic LED Button Service Client
 

#ifndef BLE_LBS_C_ENABLED
#define BLE_LBS_C_ENABLED 0
#endif

// <q> BLE_LBS_ENABLED  - ble_lbs - LED Button Service
 

#ifndef BLE_LBS_ENABLED
#define BLE_LBS_ENABLED 0
#endif

// <q> BLE_LLS_ENABLED  - ble_lls - Link Loss Service
 

#ifndef BLE_LLS_ENABLED
#define BLE_LLS_ENABLED 0
#endif

// <q> BLE_NUS_C_ENABLED  - ble_nus_c - Nordic UART Central Service
 

#ifndef BLE_NUS_C_ENABLED
#define BLE_NUS_C_ENABLED 0
#endif

// <q> BLE_NUS_ENABLED  - ble_nus - Nordic UART Service
 

#ifndef BLE_NUS_ENABLED
#define BLE_NUS_ENABLED 0
#endif

// <q> BLE_RSCS_C_ENABLED  - ble_rscs_c - Running Speed and Cadence Client
 

#ifndef BLE_RSCS_C_ENABLED
#define BLE_RSCS_C_ENABLED 0
#endif

// <q> BLE_RSCS_ENABLED  - ble_rscs - Running Speed and Cadence Service
 

#ifndef BLE_RSCS_ENABLED
#define BLE_RSCS_ENABLED 0
#endif

// <q> BLE_TPS_ENABLED  - ble_tps - TX Power Service
 

#ifndef BLE_TPS_ENABLED
#define BLE_TPS_ENABLED 0
#endif

// </h> 
//==========================================================

// <h> nRF_Drivers 

//==========================================================
// <e> ADC_ENABLED - nrf_drv_adc - Driver for ADC peripheral (nRF51)
//==========================================================
#ifndef ADC_ENABLED
#define ADC_ENABLED 1
#endif
#if  ADC_ENABLED
// <o> ADC_CONFIG_IRQ_PRIORITY  - Interrupt priority
 

// <i> Priorities 0,2 (nRF51) and 0,1,4,5 (nRF52) are reserved for SoftDevice
// <0=> 0 (highest) 
// <1=> 1 
// <2=> 2 
// <3=> 3 

#ifndef ADC_CONFIG_IRQ_PRIORITY
#define ADC_CONFIG_IRQ_PRIORITY 3
#endif
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

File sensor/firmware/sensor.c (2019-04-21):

#include "sensor.h"

#include "app_timer.h"
#include "nrf_drv_spi.h"
#include "nrf_gpio.h"
#include "nrf_drv_adc.h"


#define NRF_LOG_MODULE_NAME "SENSOR"
#define NRF_LOG_LEVEL 0
#include "nrf_log.h"
#include "nrf_log_ctrl.h"

#define BME280_SPI_BUFFER_LEN 32
#define BME280_SPI_CS_PIN 5
#define BME280_SPI_SCK_PIN 1
#define BME280_SPI_MOSI_PIN 3
#define BME280_SPI_MISO_PIN 2

#define BME280_RA_MEASURMENT_DATA 0xF7 // 8 bytes
#define BME280_RA_CTRL_MEAS 0xF4
#define BME280_RA_CTRL_HUM 0xF2
#define BME280_RA_CHIP_ID 0xD0 // must be 0x60
#define BME280_RA_CALIB00 0x88 //26bytes
#define BME280_RA_CALIB26 0xE1 //16bytes

#define SENSOR_MEASUREMENT_WAIT_TIME 100
#define BATTERY_ADC_RESULT_AVERAGE_CNT   10

#define MARGE_16BIT(H, L) ((((uint16_t)H) << 8) | ((uint16_t)L))
#define MARGE_20BIT(H, L, XL) ((((uint32_t)H) << 12) | (((uint32_t)L) << 4) | (((uint32_t)XL) >> 4))

// ADC config
// reference : internal 1.2V
// input : VDD / 3
static const nrf_drv_adc_channel_t adc_channel_config =
    {{{.resolution = NRF_ADC_CONFIG_RES_10BIT,
       .input = NRF_ADC_CONFIG_SCALING_SUPPLY_ONE_THIRD,
       .reference = NRF_ADC_CONFIG_REF_VBG,
       .ain = NRF_ADC_CONFIG_INPUT_DISABLED}}};

static const nrf_drv_adc_config_t adc_config = NRF_DRV_ADC_DEFAULT_CONFIG;

// SPI config
static nrf_drv_spi_config_t spi_config =
    {
        .ss_pin = NRF_DRV_SPI_PIN_NOT_USED,
        .sck_pin = BME280_SPI_SCK_PIN,
        .mosi_pin = BME280_SPI_MOSI_PIN,
        .miso_pin = BME280_SPI_MISO_PIN,
        .irq_priority = SPI_DEFAULT_CONFIG_IRQ_PRIORITY,
        .orc = 0xAA,
        .frequency = NRF_DRV_SPI_FREQ_1M,
        .mode = NRF_DRV_SPI_MODE_0,
        .bit_order = NRF_DRV_SPI_BIT_ORDER_MSB_FIRST};

static const nrf_drv_spi_t m_bme280_spi_master = NRF_DRV_SPI_INSTANCE(0);
static uint8_t m_bme280_spi_tx_buffer[BME280_SPI_BUFFER_LEN]; ///< SPI master TX buffer.
static uint8_t m_bme280_spi_rx_buffer[BME280_SPI_BUFFER_LEN]; ///< SPI master RX buffer.
static volatile bool m_bme280_spi_transfer_completed = false;

static sensor_data_handler_t m_sensor_data_handler = NULL;
static volatile bool m_bme280_receiving_measurement_data = false;
static SensorMeasurementData m_sensor_measurment_data;

// to calc moving average of battery adc result, use the following buffer and index as circular buffer
static uint32_t m_battery_adc_result_buffer[BATTERY_ADC_RESULT_AVERAGE_CNT];
static uint8_t m_battery_adc_result_buffer_index;
static bool m_is_first_measurement;
static nrf_adc_value_t m_battery_adc_result;


APP_TIMER_DEF(m_sensor_measurement_wait_timer_id);

// calibration parameters
// details are in datesheet of BME280
static struct
{
    uint16_t dig_T1;
    int16_t dig_T2;
    int16_t dig_T3;
    uint16_t dig_P1;
    int16_t dig_P2;
    int16_t dig_P3;
    int16_t dig_P4;
    int16_t dig_P5;
    int16_t dig_P6;
    int16_t dig_P7;
    int16_t dig_P8;
    int16_t dig_P9;
    uint8_t dig_H1;
    int16_t dig_H2;
    uint8_t dig_H3;
    int16_t dig_H4;
    int16_t dig_H5;
    int8_t dig_H6;
    int32_t t_fine;
} m_bme280_calib_data;


static void bme280_spi_master_event_handler(nrf_drv_spi_evt_t const *p_event);

static void bme280_spi_assert_cs()
{
    nrf_gpio_pin_clear(BME280_SPI_CS_PIN);
}

static void bme280_spi_deassert_cs()
{
    nrf_gpio_pin_set(BME280_SPI_CS_PIN);
}

static uint32_t bme280_spi_start_write_reg_byte(uint8_t reg_addr, uint8_t data)
{
    uint32_t err_code;

    m_bme280_spi_tx_buffer[0] = reg_addr & 0x7f;
    m_bme280_spi_tx_buffer[1] = data;

    m_bme280_spi_transfer_completed = false;

    err_code = nrf_drv_spi_init(&m_bme280_spi_master, &spi_config, bme280_spi_master_event_handler);
    if (err_code != NRF_SUCCESS)
    {
        return err_code;
    }

    bme280_spi_assert_cs();
    err_code = nrf_drv_spi_transfer(&m_bme280_spi_master, m_bme280_spi_tx_buffer, 2, m_bme280_spi_rx_buffer, 2);

    return err_code;
}

static uint32_t bme280_spi_start_read_reg_bytes(uint8_t reg_addr, uint8_t len)
{
    uint32_t err_code;

    m_bme280_spi_tx_buffer[0] = reg_addr | 0x80;
    m_bme280_spi_tx_buffer[1] = 0x00;

    m_bme280_spi_transfer_completed = false;

    err_code = nrf_drv_spi_init(&m_bme280_spi_master, &spi_config, bme280_spi_master_event_handler);
    if (err_code != NRF_SUCCESS)
    {
        return err_code;
    }

    bme280_spi_assert_cs();
    err_code = nrf_drv_spi_transfer(&m_bme280_spi_master, m_bme280_spi_tx_buffer, len + 1, m_bme280_spi_rx_buffer, len + 1);

    return err_code;
}

static void bme280_spi_wait_for_transfer_complete()
{
    while (!m_bme280_spi_transfer_completed)
        ;
    nrf_drv_spi_uninit(&m_bme280_spi_master);
}

// calibration code is cited from below url.
// https://github.com/BoschSensortec/BME280_driver
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

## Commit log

2018-12-03 sensor pcb：add pcb data
    [ENBLE.kicad_pcb, ENBLE.sch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]
2018-12-20 sensor firm: copy base from nordic template
2018-12-20 sensor firm: implement BLE service
2018-12-27 sensor firm: implement manipulations for led and button
2018-12-27 sensor firm: implement manipulations for BME280
2018-12-29 sensor firm: implement ENBLE application
    * periodically sensor measurement
    * sending measurement on advertise data
2018-12-29 sensor firm: improve sensor measuring * rename bme280 module * add measuring of battery voltage * add uninit spi and adc after using them to reduce current consumption
2018-12-29 sensor firm: fix sign of temperature
    [sensor.c]
2018-12-29 sensor firm: add user descriptions to charactericsis
2018-12-29 sensor firm: fix not applying wrote data through ENBLE service
    * add properly calling event handler of ENBLE service
    * change how to store sensor measurement
    * add procedure of updating advertising data after new device_id is written
    [main.c]
2018-12-29 sensor firm: add restart of advertising after disconnect
2018-12-30 sensor firm: add backup device id and measurement period using FDS
2019-01-04 sensor firm: change an order of data in advertise packets
2019-01-04 sensor firm: update README about advertising
2019-01-07 sensor firm: add frequently advertising when button is pushed
2019-01-07 sensor firm: improve error log
    [main.c]
2019-01-07 sensor firm: add clearing nonvolatile data
    If button is pushed in boot sequence, nonvolatile data (measurement period, device id and bonding data) will be cleared.
2019-01-31 sensor firm: optimize current consumption
    * fix compiler option -Og to -O2
    * remove logging via SeggerRTT
    * remove led blinking at the end of sensor measurement
    [main.c, sensor.c]
2019-04-01 sensor firm: smooth battery measurement value
    to get smooth one, use the moving average of battery voltage as battery voltage measurement
2019-04-01 sensor firm: fix ignore condition for a button event
    [led_button.c]
2019-04-02 sensor firm: blink led at writing period char or device_id char
2019-04-04 sensor firm: change units of measured value
2019-04-16 sensor firm: change advertising interval
    to reduce current consumption
2019-04-16 sensor pcb: move library files into lib directory
    [ENBLE.kicad_pcb, ENBLE.sch]
2019-04-17 sensor: add script to calcurate current consumption
2019-04-20 sensor: update README
